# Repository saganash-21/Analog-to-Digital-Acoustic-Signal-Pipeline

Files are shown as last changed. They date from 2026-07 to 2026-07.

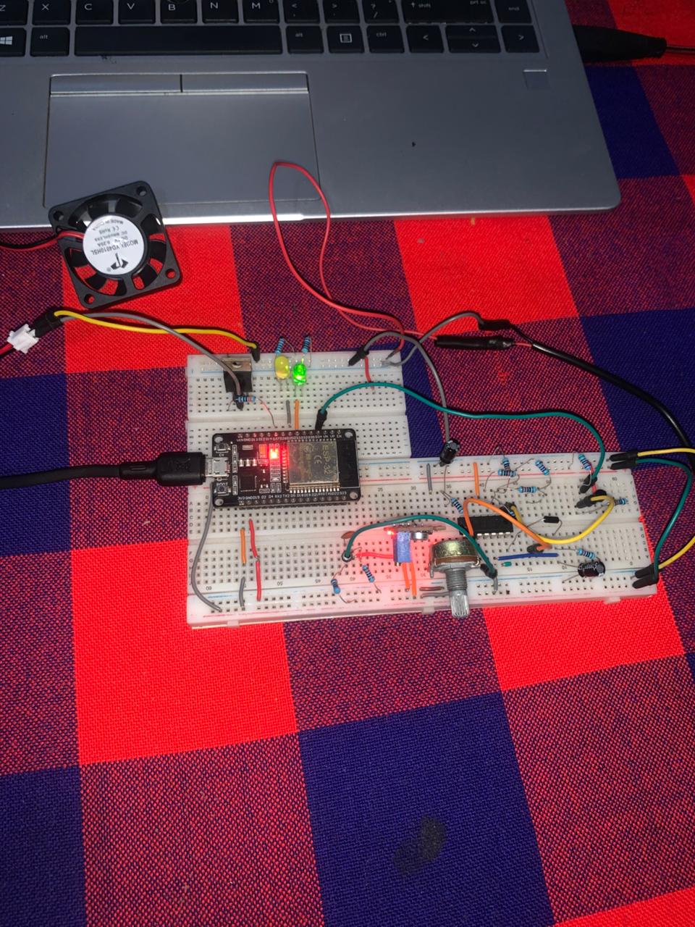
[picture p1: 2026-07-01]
media/Breadboard layout.jpeg

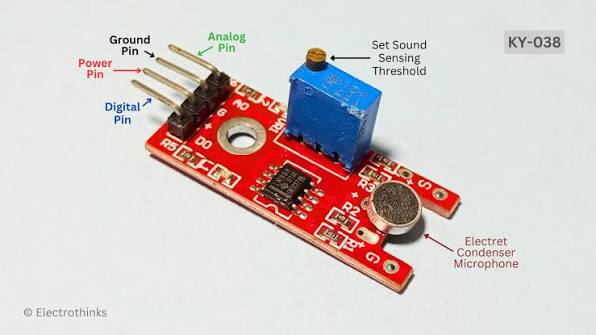
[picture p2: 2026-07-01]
media/KY308.jpg

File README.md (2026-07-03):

# Analog-to-Digital Acoustic Signal Pipeline & Isolated Load Controller
Jeremy Ndirangu

## ⚙️ Executive Summary
This project demonstrates a robust, custom-built analog signal conditioning pipeline designed to extract discrete, reliable logic triggers from a chaotic acoustic environment. To validate the system's industrial applicability, the processed digital signal bridges a mixed-voltage logic gap to control an ESP32 hardware interrupt, which subsequently drives a high-current inductive DC motor.

## 🏗️ System Architecture & Signal Journey
The architecture deliberately avoids monolithic sensor modules in favor of discrete signal conditioning. This ensures absolute control over hysteresis, voltage boundaries, and power isolation across distinct domains.

*   **1. Transducer Stage:** A KY-038 Electret Microphone converts raw physical air pressure into an Alternating Current (AC) wave superimposed on a 1.48V DC baseline.
*   **2. Analog Conditioning Stage:** An operational amplifier is biased with a 10 kΩ voltage divider to establish a 1.65V virtual ground. A 0.1 µF coupling capacitor establishes a 318.3 Hz high-pass filter to block environmental rumble. The signal then passes through a non-inverting amplifier configured with a 101x operational gain, scaling a nominal 20 mV acoustic spike into a 2.2V AC swing.
*   **3. Envelope Detector & Unity Buffer:** A half-wave rectifier diode strips the negative AC wave, charging a parallel RC tank circuit. The 10 µF capacitor and 10 kΩ resistor stretch the microsecond transient into a sustained 0.1-second DC logic envelope, which is then stabilized by a unity gain buffer.
*   **4. Digitizer & Logic Level Bridge:** A Schmitt Trigger configuration establishes a strict upper trip point of 1.05V and a lower trip point of 0.99V to eliminate signal chattering. This generates a clean 1.95V digital edge. A discrete 2N2222 NPN transistor operates as an inverting logic level shifter to bridge the 1.95V signal safely into the 3.3V domain.
*   **5. Firmware Engine (Digital Stage):** `IRAM_ATTR` hardware interrupts on the ESP32 catch the physical digital edge, deploying a mathematical debounce window to reject reverberations.
*   **6. Solid-State Actuation & Protection:** The ESP32 drives an N-Channel MOSFET (M1) via a 330 Ω series resistor, limiting instantaneous inrush current to the parasitic gate capacitance. The MOSFET controls a 5V Brushless DC (BLDC) fan. A 1N4004 flyback diode is placed in parallel across the fan load to provide a safe recirculation path for destructive back-EMF spikes during motor cutoff.
*   **7. Visual Status Indication:** Dedicated Yellow and Green LEDs provide hardware-level diagnostic feedback. Each LED is driven by isolated logic pins and protected by a 220 Ω current-limiting resistor tied directly to ground.

## 📐 Hardware Design Constraints
This system enforces a strict hardware design constraint at the logic bridge: the collector of the NPN transistor is tied to the 3.3V logic domain exclusively via a physical 5.1 kΩ external pull-up resistor. 

Internal microcontroller pull-ups are strictly prohibited in this design architecture. The physical 5.1 kΩ pull-up guarantees a pristine, high-current logic HIGH when the transistor is in cutoff, completely eliminating floating inputs and ensuring industrial-grade signal stability before the hardware interrupt is fired.

## 🧮 Mathematical Design & Schematics
*   **System Mathematics:** Detailed mathematical derivations for the op-amp gain stages, RC time constants, virtual ground bridging, and Schmitt trigger hysteresis are documented in `docs/System_Design_Criteria.pdf`.
*   **Wiring Diagram:** The complete mixed-signal PCB routing drafted in Eagle CAD is available in `schematics/Complete_Circuit_Diagram.pdf`.
*   **System Flow:** The high-level data pipeline mapping is available in `docs/Block_Diagram.png`.

## 💻 Firmware
The C++ logic is entirely interrupt-driven, minimizing processor polling cycles and allowing for concurrent operations. The source code is available in `firmware/main`.

## ## 📊 Bill of Materials
| Stage | Component | Role |
| :--- | :--- | :--- |
| **Transducers** | KY-038 Electret Mic | Acoustic-to-electrical signal conversion. |
| **Analog Pre-Amp** | LM324 Quad Op-Amp | 101x non-inverting gain & virtual ground biasing. |
| **Envelope Detection** | 1N4004 Power Diode | Half-wave rectification for AC-to-DC envelope conversion. |
| **Logic Thresholding** | LM324 Op-Amp | Hysteresis-based Schmitt Trigger digitizer. |
| **Level Shifter** | 2N2222 NPN BJT | Isolated logic translation (1.95V to 3.3V). |
| **Logic Controller** | ESP32 Microcontroller | Interrupt-driven signal processing & state logic. |
| **Power Switching** | IRLZ44N N-Channel MOSFET | Logic-level high-current inductive load control. |
| **Load Protection** | 1N4004 Flyback Diode | Inductive kickback clamping for motor safety. |
| **Actuation** | 5v BLDC Fan | Fan spinning |
| **Diagnostic** | Yellow/Green LEDs | Real-time hardware-level system status indication. |

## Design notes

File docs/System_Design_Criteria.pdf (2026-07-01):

## Engineering Design Document: System Mathematics & Analog Conditioning

Author: Jeremy Ndirangu
This document details the theoretical calculations, physical principles, and integrated design constraints governing the analog signal conditioning pipeline and digital logic bridge.
1. High-Pass Filter & Virtual Ground Stage

Raw acoustic signals from the electret microphone arrive as Alternating Current (AC) waves superimposed on a 1.48V DC baseline. To amplify this wave without clipping against the ground rail, the operational amplifier requires a synthetic midpoint.
A voltage divider constructed from two 10 kΩ resistors biases the 3.3V supply to establish a stable 1.65V virtual ground. This specific resistance value provides a sufficiently stiff bias current to the op-amp input while minimizing parasitic power loss from the main supply.
A 0.1 µF coupling capacitor acts as a DC-blocking filter between the transducer and the pre-amp. To steady 0 Hz DC signals, the capacitor presents infinite resistance, completely isolating the microphone’s native bias. Conversely, it presents near-zero resistance to high-frequency AC audio transients. The equivalent resistance of the voltage divider is calculated as:

R

eq =

10000·10000
10000+10000 = 5000 Ω

This yields a lower cut-off frequency of:

f

c =

1
2π·R
eq

·C =

1
2π·5000· 0.1×10

−6
( )

≈ 318. 3 Hz

This 318.3 Hz cut-off intentionally attenuates low-frequency environmental noise, such as HVAC rumble or footsteps, while allowing high-frequency acoustic transients—such as a hand clap—to pass into the amplification stage unimpeded.
2. Pre-Amplifier Gain Stage (Non-Inverting)

The filtered acoustic transient requires voltage scaling to be readable by logic gates. This is achieved by configuring the Op Amp as a non-inverting amplifier, where the gain (A ) is governed by the feedback resistor ( ) and the input resistor ( ):
v

R
f

R
in

A

v = 1 +

R
f
R
in

The hardware utilizes a 10 kΩ potentiometer for R and a 100 Ω fixed resistor for ,
f

R
in
which is placed in series with a 10 µF capacitor to ground.
At the 0 Hz DC baseline, the 10 µF capacitor acts as an open circuit, driving the denominator toward infinity and resulting in a unity gain (1 ×).
This ensures the 1.65V virtual ground is perfectly stable and not erroneously amplified into the voltage rails. For fast-moving AC transients exceeding 1000 Hz, the capacitor acts as a short circuit, allowing the system to achieve its maximum operational gain:

A

v = 1 +

10000
100 = 101 × Gain

This 101x multiplier successfully scales a nominal 20 mV acoustic spike into a 2.2V AC swing, preparing it for the logic thresholding stages.

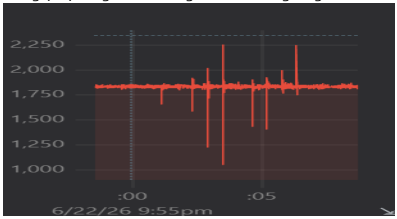
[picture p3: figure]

3. Envelope Detector & Unity Gain Buffer

Because digital microcontrollers cannot efficiently process jagged, bidirectional AC waves, this stage rectifies and stretches the transient into a sustained DC logic level. A half-wave rectifier diode blocks reverse current flow, stripping the negative half of the AC wave and passing only the positive voltage peaks.
These positive peaks charge a parallel RC tank circuit. Due to the diode blocking reverse flow, the 10 µF capacitor must discharge exclusively through a 10 kΩ parallel resistor to ground. The discharge speed is dictated by the time constant (τ):

τ = R · C = 10000 · 10 × 10⁻⁶
( | ) = 0. 1 seconds

An acoustic clap lasts less than 5 milliseconds, meaning a raw peak could easily be missed by a microcontroller interrupt.
The 0.1-second time constant physically stretches the microsecond event into a wide, sustained DC envelope, guaranteeing digital capture.

The envelope then passes through a unity gain buffer wired as a voltage follower. This provides infinite input impedance and zero output impedance, acting as a robust power supply for the signal. It strictly prevents the subsequent logic stages from drawing current and prematurely draining the RC tank.

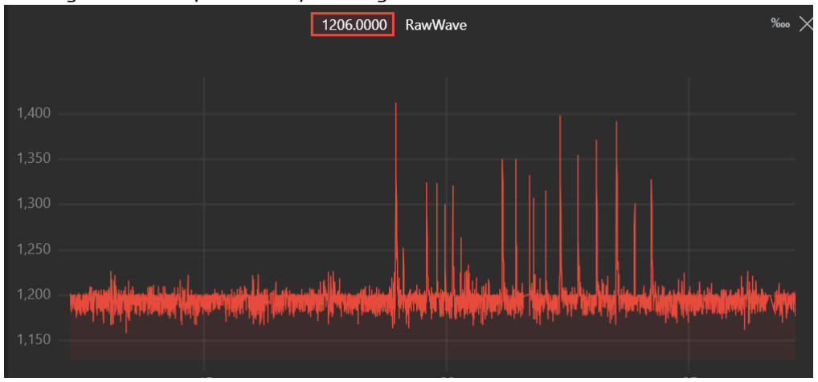
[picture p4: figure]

4. Schmitt Trigger Digitization

To transition from analog conditioning to digital logic without introducing signal chattering, the final op-amp is configured as a Schmitt trigger. The integrated resistor network establishes dual trip points (hysteresis) dictated by the feedback equation:

V

+ = V

buffer + V

o − V
buffer
( | ) ×

R
in
R

in+R
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
This configuration establishes a strict upper trip point of 1.05V and a lower trip point of 0.99V.
By requiring the rising envelope to cross 1.05V to trigger a HIGH state, and forcing it to decay below 0.99V before returning to a LOW state, the hardware enforces a singular, bounce-free digital edge.
This dual-threshold approach renders the system entirely immune to room echoes or minor voltage fluctuations hovering near the baseline.
5. Logic Level Bridge & Isolation Constraints

The Schmitt trigger generates a 1.95V digital output edge. This voltage level is unstable and unreliable for driving standard 3.3V logic processors.
A discrete 2N2222 NPN transistor is deployed as an isolating logic level shifter to safely bridge this gap.

The system enforces a strict hardware design constraint at this bridge: the collector of the NPN transistor is tied to the 3.3V logic domain exclusively via a physical 5.1 kΩ external pull-up resistor.
Internal microcontroller pull-ups are strictly prohibited in this design architecture. The physical 5.1 kΩ pull-up guarantees a pristine, high-current logic HIGH when the transistor is in cutoff, completely eliminating floating inputs and ensuring industrial-grade signal stability before the hardware interrupt is fired.

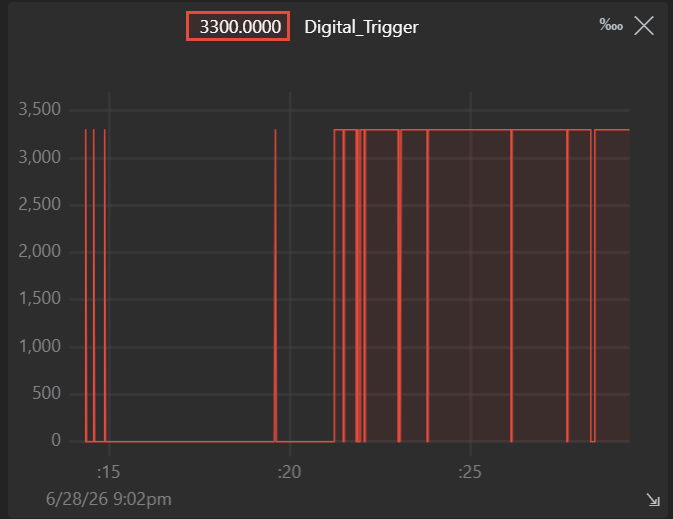
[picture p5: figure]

6. Solid-State Actuation & Inductive Load Protection
The pristine digital edge captured by the logic stage triggers the ESP32 microcontroller, which is responsible for driving an N-Channel MOSFET (M1) to control a 5V Brushless DC (BLDC) fan. The microcontroller interfaces with the MOSFET gate via a 330Ω series resistor. This specific resistance limits the instantaneous inrush current required to charge the MOSFET’s parasitic gate capacitance, protecting the logic pins from overcurrent transients while ensuring rapid switching.

Because the BLDC fan represents a highly inductive load, the sudden interruption of current by the MOSFET going into cutoff will generate a destructive high-voltage back-electromotive force (back-EMF) spike. To mitigate this, a 1N4004 flyback diode is placed in parallel across the fan load. When the MOSFET disengages, this diode provides an immediate, safe recirculation path for the inductive kickback, clamping the transient voltage and preventing avalanche breakdown of the MOSFET.

7. Visual Status Indication
To provide immediate, hardware-level diagnostic feedback without relying on serial monitors, the system features a dedicated status bar. This consists of Yellow and Green LEDs, each driven by isolated logic pins. To ensure the forward current remains well within the safe operational limits of both the semiconductor diodes and the logic controller, each LED is placed in series with a 220 Ω current-limiting resistor tied directly to ground.

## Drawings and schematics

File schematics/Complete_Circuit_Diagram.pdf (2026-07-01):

# R5 R⁶

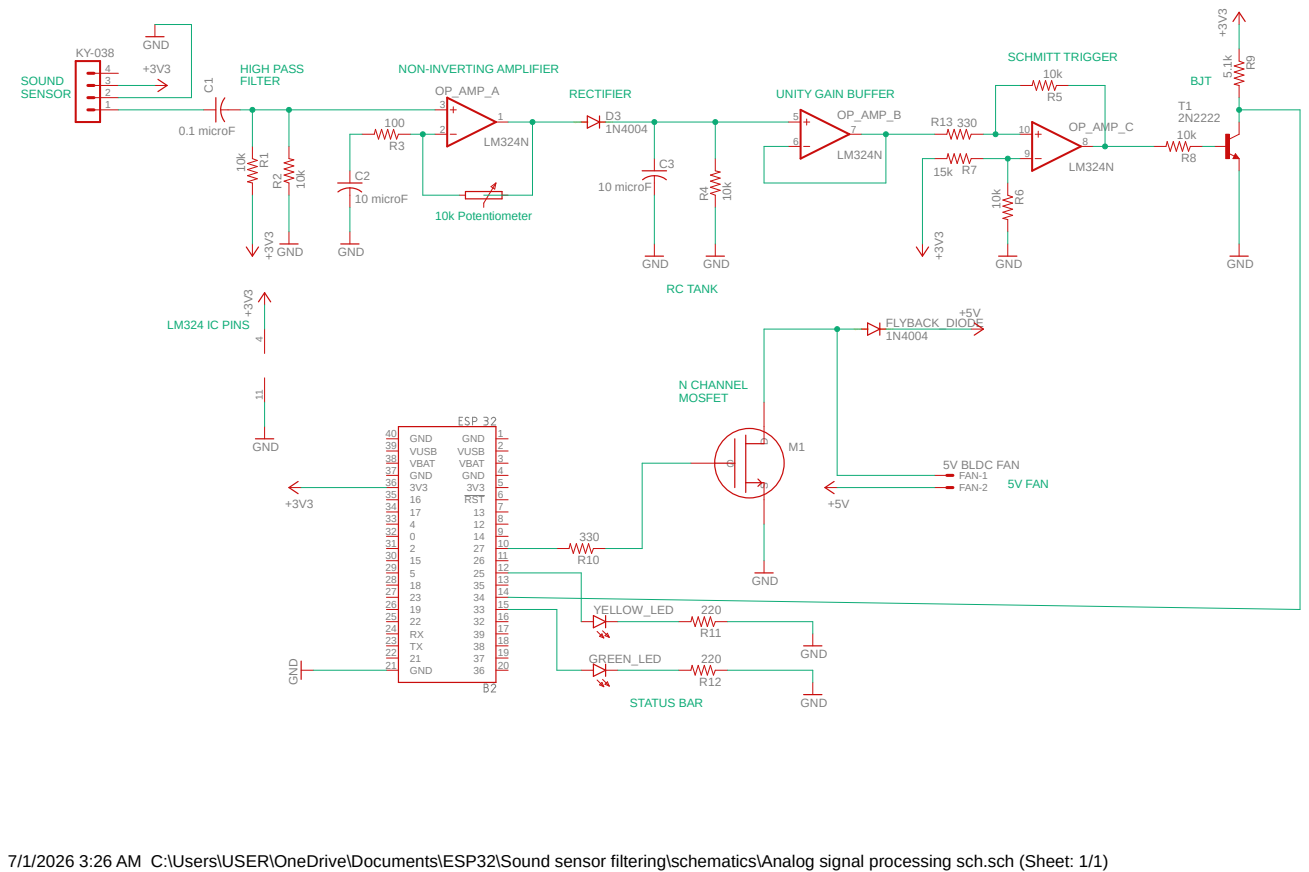
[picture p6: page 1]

7/1/2026 3:26 AM C:\Users\USER\OneDrive\Documents\ESP32\Sound sensor filtering\schematics\Analog signal processing sch.sch (Sheet: 1/1)

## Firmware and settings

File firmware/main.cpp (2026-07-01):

#include <Arduino.h>

// --- Pin Definitions ---
const int CLAP_PIN = 34;   // Input from NPN Collector
const int FAN_PIN = 27;    // Output to MOSFET Gate
const int GREEN_LED = 33;    // Output to Red Gate
const int YELLOW_LED = 25;    // Output to yellow LED



volatile bool fanState = false;
volatile bool clapDetected = false; // Flag for the Serial monitor
volatile unsigned long lastClapTime = 0;
const unsigned long debounceDelay = 500;

void IRAM_ATTR handleClap() {
  unsigned long currentTime = millis();
  if ((currentTime - lastClapTime) > debounceDelay) {
    fanState = !fanState;
    clapDetected = true; // Tell the main loop to print a message
    lastClapTime = currentTime;
  }
}

void setup() {
  Serial.begin(115200); // Start serial communication
  Serial.println("ESP32 Clap Switch Ready. Waiting for sound...");
  
  pinMode(CLAP_PIN, INPUT); 
  pinMode(FAN_PIN, OUTPUT);
  pinMode(GREEN_LED, OUTPUT);
  pinMode(YELLOW_LED, OUTPUT);
  digitalWrite(FAN_PIN, LOW);
  digitalWrite(GREEN_LED, LOW);
  digitalWrite(YELLOW_LED, HIGH);

  attachInterrupt(digitalPinToInterrupt(CLAP_PIN), handleClap, FALLING);
}

void loop() {
  if (clapDetected) {
    Serial.print("Clap heard! Fan State is now: ");
    Serial.println(fanState ? "ON" : "OFF");
    clapDetected = false; // Reset the flag
  }
  
  digitalWrite(FAN_PIN, fanState ? HIGH : LOW);
  digitalWrite(YELLOW_LED, fanState ? HIGH : LOW);
  digitalWrite(GREEN_LED, fanState ? LOW : HIGH);
}
